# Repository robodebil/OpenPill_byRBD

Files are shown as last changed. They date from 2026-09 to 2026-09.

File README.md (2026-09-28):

# OpenPill_byRBD
STM32F107VCT6 devboard for DIY PCB Transfer. 1 layer, second lay is jumper

In the near future, I will etch the printed circuit board and post the result a bit later.

I know there are some issues; I’ll do my best to fix them.



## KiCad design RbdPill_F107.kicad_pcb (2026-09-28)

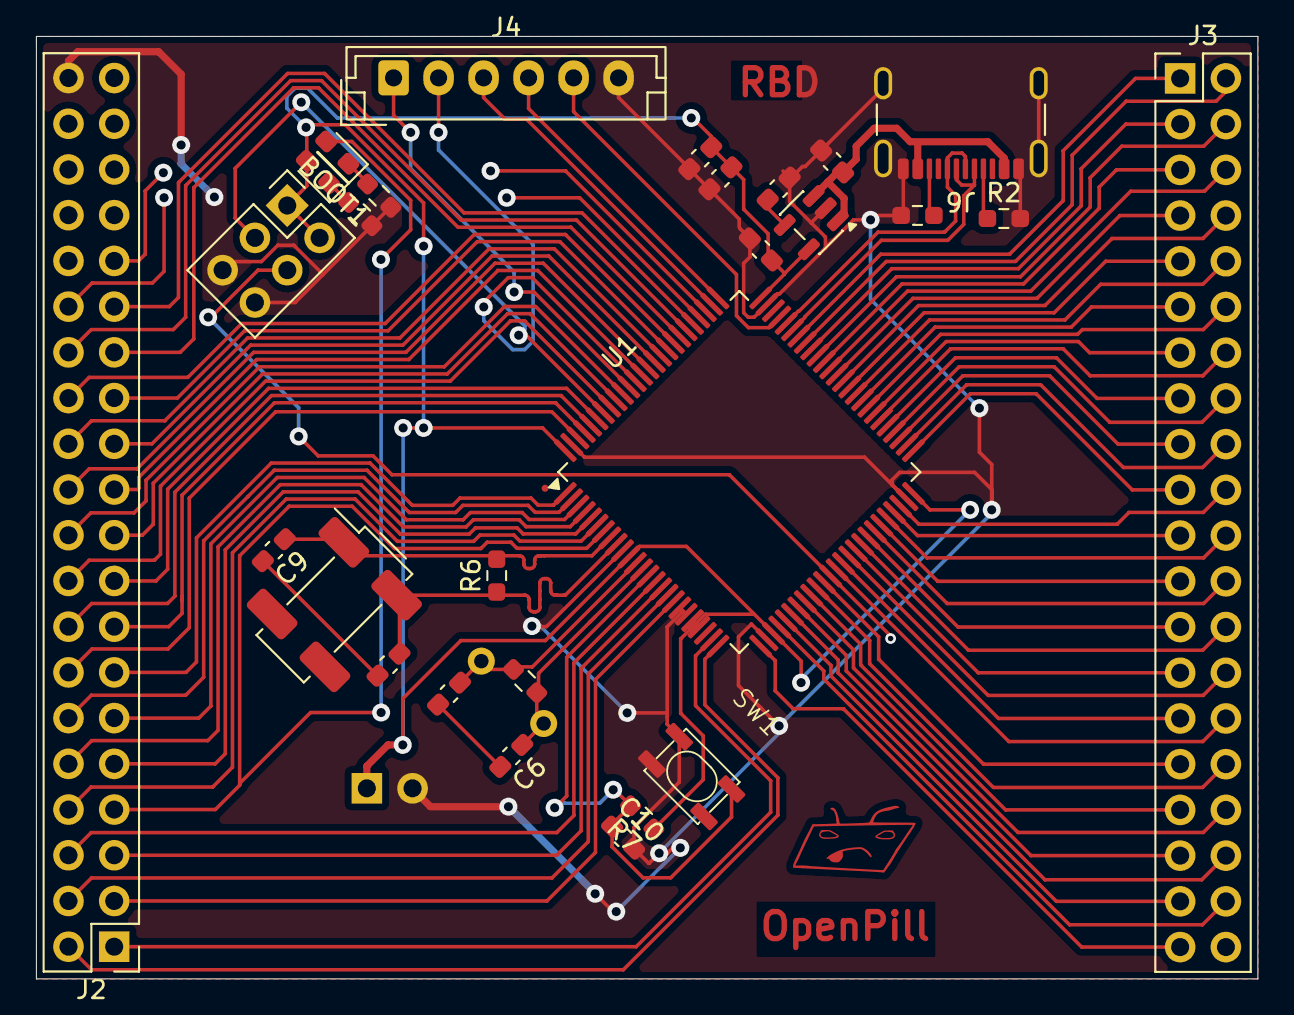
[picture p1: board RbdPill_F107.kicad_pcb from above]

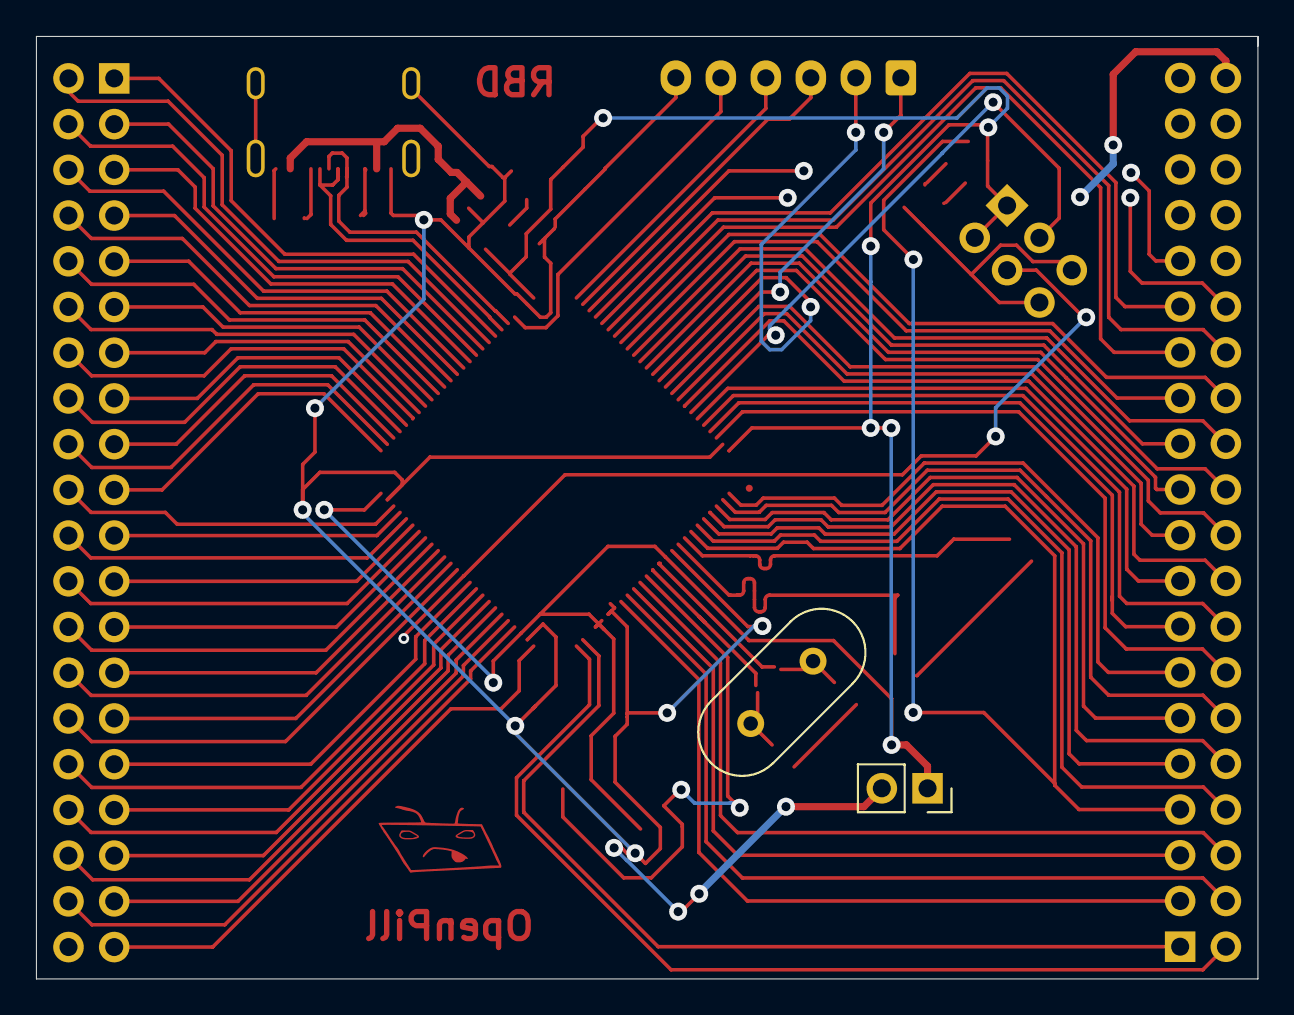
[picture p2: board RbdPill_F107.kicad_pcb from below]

Board: 2 copper layers, 67.9 x 52.4 mm, 30 parts (2 on the bottom side), 94 nets.

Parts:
BOOT1: Conn_02x03_Odd_Even; PinHeader_2x03_P2.54mm_Vertical
C1, C2: 1 uF; C_0603_1608Metric_Pad1.08x0.95mm_HandSolder
C3: 10 nF; C_0603_1608Metric_Pad1.08x0.95mm_HandSolder
C4, C5: 100 nF; C_0603_1608Metric_Pad1.08x0.95mm_HandSolder
C6, C7, C8, C9: 40 pF; C_0603_1608Metric_Pad1.08x0.95mm_HandSolder
C10: 0.1 uF; C_0603_1608Metric_Pad1.08x0.95mm_HandSolder
D1, D2: LED; LED_0603_1608Metric_Pad1.05x0.95mm_HandSolder
J1: Conn_01x02; PinSocket_1x02_P2.54mm_Vertical
J2, J3: Conn_02x20_Counter_Clockwise; PinHeader_2x20_P2.54mm_Vertical
J4: Conn_01x06; JST_EH_B6B-EH-A_1x06_P2.50mm_Vertical
J6: USB_C_Receptacle_USB2.0_16P; USB_C_Receptacle_GCT_USB4105-xx-A_16P_TopMnt_Horizontal
R1, R6: 1 MOhm; R_0603_1608Metric_Pad0.98x0.95mm_HandSolder
R2, R3: 5.1 kOhm; R_0603_1608Metric_Pad0.98x0.95mm_HandSolder
R4, R5: 510 Ohm; R_0603_1608Metric_Pad0.98x0.95mm_HandSolder
R7: 10 kOhm; R_0603_1608Metric_Pad0.98x0.95mm_HandSolder
SW1: SW_Push; KLS7-TS3401
U1: STM32F107VCTx; LQFP-100_14x14mm_P0.5mm
U3: LD3985M33R_SOT23; SOT-23-5
Y1: 8 MHz; Crystal_HC18-U_Vertical
Y2: 8 MHz; Crystal_SMD_SeikoEpson_MC306-4Pin_8.0x3.2mm_HandSoldering

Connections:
+3.3V: BOOT1.1, BOOT1.2, C1.1, C4.1, C5.1, D1.2 (A), J1.1, R7.1, U1.11 (VDD), U1.21 (VREF+), U1.22 (VDDA), U1.28 (VDD), U1.50 (VDD), U1.75 (VDD), U1.100 (VDD), U3.5 (VOUT)
/BOOT0: BOOT1.3, U1.94 (BOOT0)
/BOOT1: BOOT1.4, U1.37 (PB2)
/PA1: J2.2, U1.25 (PA2)
/PA2: J2.1, U1.24 (PA1)
/PA3: J3.39, U1.26 (PA3)
/PA4: J3.38, U1.29 (PA4)
/PA5: J3.37, U1.30 (PA5)
/PA6: J3.36, U1.31 (PA6)
/PA7: J3.35, U1.32 (PA7)
/PA8: J3.3, U1.67 (PA8)
/PA9: J3.2, U1.68 (PA9)
/PA10: J3.1, U1.69 (PA10)
/PB0: J3.32, U1.35 (PB0)
/PB1: J3.31, U1.36 (PB1)
/PB5: J2.20, U1.91 (PB5)
/PB6: J2.19, U1.92 (PB6)
/PB7: J2.18, U1.93 (PB7)
/PB8: J2.17, U1.95 (PB8)
/PB9: J2.16, U1.96 (PB9)
/PB10: J3.21, U1.47 (PB10)
/PB11: J3.20, U1.48 (PB11)
/PB12: J3.19, U1.51 (PB12)
/PB13: J3.18, U1.52 (PB13)
/PB14: J3.17, U1.53 (PB14)
/PB15: J3.16, U1.54 (PB15)
/PC0: J2.6, U1.15 (PC0)
/PC1: J2.5, U1.16 (PC1)
/PC2: J2.4, U1.17 (PC2)
/PC3: J2.3, U1.18 (PC3)
/PC4: J3.34, U1.33 (PC4)
/PC6: J3.7, U1.63 (PC6)
/PC7: J3.6, U1.64 (PC7)
/PC8: J3.5, U1.65 (PC8)
/PC9: J3.4, U1.66 (PC9)
/PC10: J2.31, U1.78 (PC10)
/PC11: J2.30, U1.79 (PC11)
/PC12: J2.29, U1.80 (PC12)
/PC13: D2.2 (A), J2.7, U1.7 (PC13)
/PD0: J2.28, U1.81 (PD0)
/PD1: J2.27, U1.82 (PD1)
/PD2: J2.26, U1.83 (PD2)
/PD3: J2.25, U1.84 (PD3)
/PD4: J2.24, U1.85 (PD4)
/PD5: J2.23, U1.86 (PD5)
/PD6: J2.22, U1.87 (PD6)
/PD7: J2.21, U1.88 (PD7)
/PD8: J3.15, U1.55 (PD8)
/PD9: J3.14, U1.56 (PD9)
/PD10: J3.13, U1.57 (PD10)
/PD11: J3.12, U1.58 (PD11)
/PD12: J3.11, U1.59 (PD12)
/PD13: J3.10, U1.60 (PD13)
/PD14: J3.9, U1.61 (PD14)
/PD15: J3.8, U1.62 (PD15)
/PE0: J2.15, U1.97 (PE0)
/PE1: J2.14, U1.98 (PE1)
/PE2: J2.13, U1.1 (PE2)
/PE3: J2.12, U1.2 (PE3)
/PE4: J2.11, U1.3 (PE4)
/PE5: J2.10, U1.4 (PE5)
/PE6: J2.9, U1.5 (PE6)
/PE7: J3.30, U1.38 (PE7)
/PE8: J3.29, U1.39 (PE8)
/PE9: J3.28, U1.40 (PE9)
/PE10: J3.27, U1.41 (PE10)
/PE11: J3.26, U1.42 (PE11)
/PE12: J3.25, U1.43 (PE12)
/PE13: J3.24, U1.44 (PE13)
/PE14: J3.23, U1.45 (PE14)
/PE15: J3.22, U1.46 (PE15)
/PС5: J3.33, U1.34 (PC5)
/RESET: C10.1, R7.2, SW1.2, U1.14 (NRST)
/SYS_CLK: J4.4, U1.76 (PA14)
/SYS_DIO: J4.5, U1.72 (PA13)
/SYS_JTDI: J4.3, U1.77 (PA15)
/SYS_JTDO: J4.2, U1.89 (PB3)
/SYS_NJTRST: J4.1, U1.90 (PB4)
/USB_D+: J6.A6 (D+), J6.B6 (D+), U1.71 (PA12)
/USB_D-: J6.A7 (D-), J6.B7 (D-), U1.70 (PA11)
/VBAT: J2.8, U1.6 (VBAT)
GND: BOOT1.5, BOOT1.6, C1.2, C2.1, C3.1, C4.2, C5.2, C10.2, J1.2, J2.40, J4.6, J6.A1 (GND), J6.A12 (GND), J6.B1 (GND), J6.B12 (GND), J6.SH (SHIELD), R2.2, R3.1, R4.2, R5.2, SW1.1, U1.10 (VSS), U1.19 (VSSA), U1.20 (VREF-), U1.27 (VSS), U1.49 (VSS), U1.74 (VSS), U1.99 (VSS), U3.2 (GND)
unnamed: C6.2, C7.2
unnamed: C8.2, C9.2
unnamed: D1.1 (K), R4.1
unnamed: D2.1 (K), R5.1
unnamed: J6.A5 (CC1), R2.1
unnamed: J6.B5 (CC2), R3.2
unnamed: C7.1, R1.1, U1.12 (OSC_IN), Y1.2
unnamed: C6.1, R1.2, U1.13 (OSC_OUT), Y1.1
unnamed: C9.1, R6.2, U1.8 (PC14), Y2.1
unnamed: C8.1, R6.1, U1.9 (PC15), Y2.2
unnamed: C3.2, U3.4 (BYP)
VCC: C2.2, J6.A4 (VBUS), J6.A9 (VBUS), J6.B4 (VBUS), J6.B9 (VBUS), U3.1 (VIN), U3.3 (INH)
